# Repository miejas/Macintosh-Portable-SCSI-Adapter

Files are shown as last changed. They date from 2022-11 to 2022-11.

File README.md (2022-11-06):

# Macintosh Portable SCSI Adapter
An adapter from the 34-pin SCSI in the Portable to a standard 50-pin header.

Nothing fancy. Just rewires the pins in a convenient fashion, without the need for cobbling cables together. Additionally, there's an option to provide 5V to the TERMPWR pin. This could be achieved with a power diode for "high" current applications (like a SCSI to SD adapter) or a 220/330Ω resistor for current sensing only applications (as described in one of Woz's brain storm documents - can't seem to find it back).

The board has been succesfully produced by JLCPCB and Aisler, so I suppose any manufacturer of choice will do. It probably fits an entire host of different IDC connectors, but they've been succesfully fitted with Samtec's TST-125-01-G-D and TST-117-01-G-D. The 5V-GND-GND-12V "connector" could just be a floppy or hard drive wire bundle, recovered from an old ATX power supply.

The project is in KiCad format and is free for anyone to use, either personally or commercially. Since I have absolutely no experience in schematic and PCB design, there will probably be some errors and "donts". If you happen to find them, please let me know so I can adapt the design accordingly. Needless to say, but use of this project is at your own risk.

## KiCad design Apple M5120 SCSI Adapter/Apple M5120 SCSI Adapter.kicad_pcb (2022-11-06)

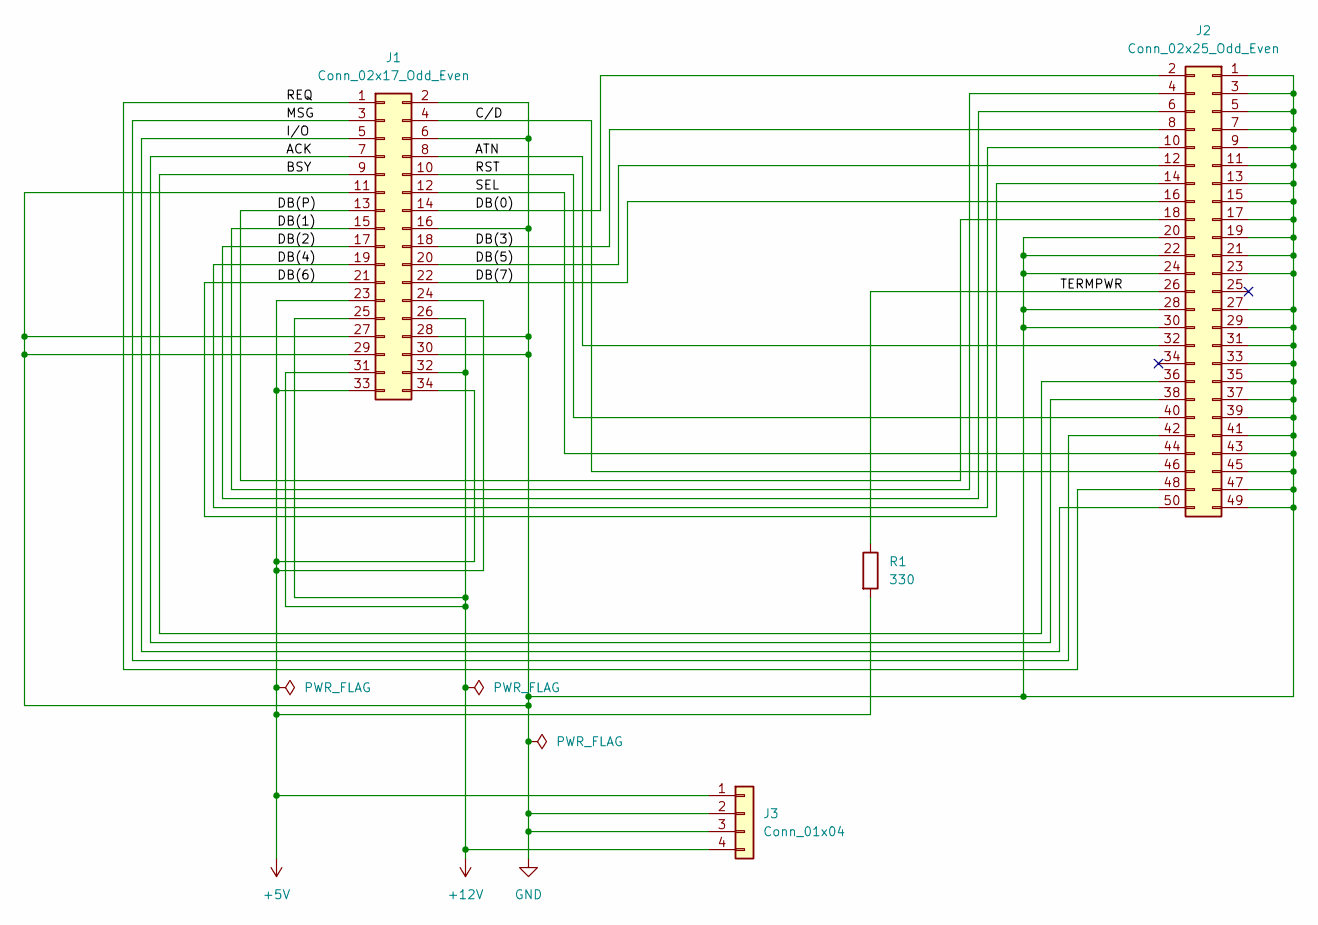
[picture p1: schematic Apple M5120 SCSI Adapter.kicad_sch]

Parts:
J1: Conn_02x17_Odd_Even; IDC-Header_2x17_P2.54mm_Vertical
J2: Conn_02x25_Odd_Even; IDC-Header_2x25_P2.54mm_Vertical
J3: Conn_01x04; SolderWire-0.75sqmm_1x04_P7mm_D1.25mm_OD3.5mm
R1: 330; R_Axial_DIN0207_L6.3mm_D2.5mm_P15.24mm_Horizontal

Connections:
+5V: J1.23, J1.24, J1.33, J1.34, J3.1, R1.2
+12V: J1.25, J1.26, J1.31, J1.32, J3.4
/ACK: J1.7, J2.38
/ATN: J1.8, J2.32
/BSY: J1.9, J2.36
/C/D: J1.4, J2.46
/DB(0): J1.14, J2.2
/DB(1): J1.15, J2.4
/DB(2): J1.17, J2.6
/DB(3): J1.18, J2.8
/DB(4): J1.19, J2.10
/DB(5): J1.20, J2.12
/DB(6): J1.21, J2.14
/DB(7): J1.22, J2.16
/DB(P): J1.13, J2.18
/I/O: J1.5, J2.50
/MSG: J1.3, J2.42
/REQ: J1.1, J2.48
/RST: J1.10, J2.40
/SEL: J1.12, J2.44
/TERMPWR: J2.26, R1.1
GND: J1.2, J1.6, J1.11, J1.16, J1.27, J1.28, J1.29, J1.30, J2.1, J2.3, J2.5, J2.7, J2.9, J2.11, J2.13, J2.15, J2.17, J2.19, J2.20, J2.21, J2.22, J2.23, J2.24, J2.27, J2.28, J2.29, J2.30, J2.31, J2.33, J2.35, J2.37, J2.39, J2.41, J2.43, J2.45, J2.47, J2.49, J3.2, J3.3

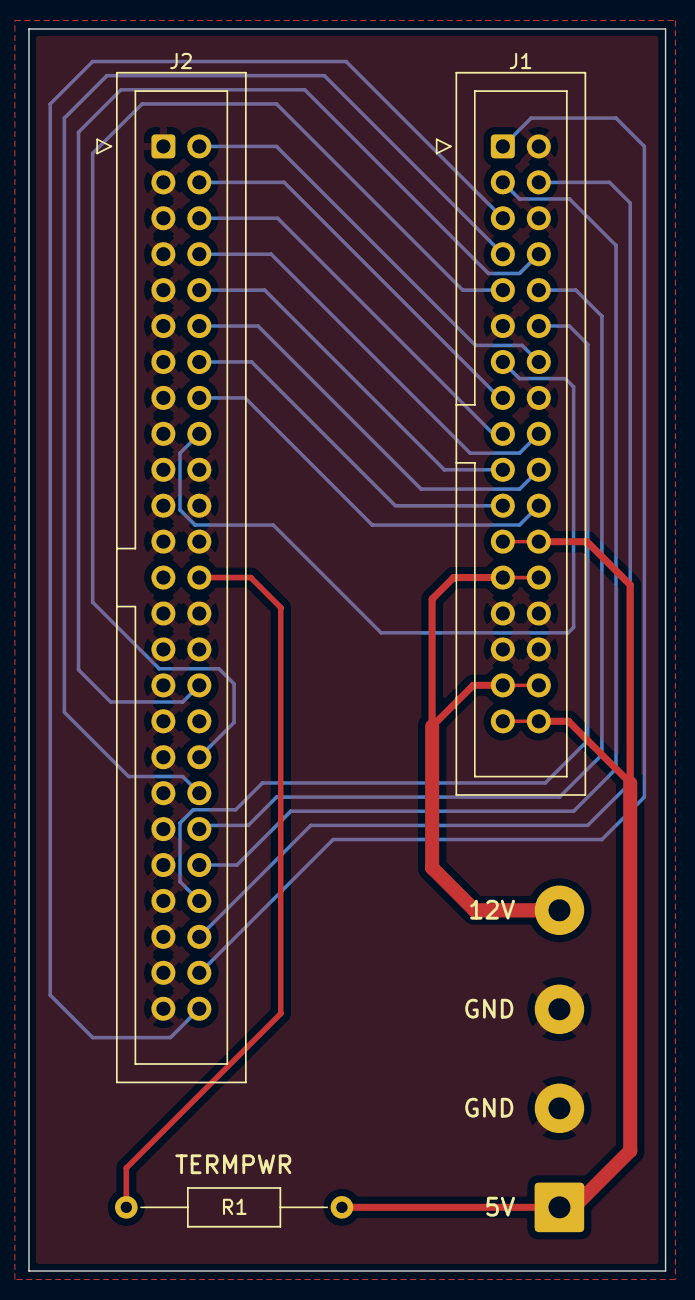
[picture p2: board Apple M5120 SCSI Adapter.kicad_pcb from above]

Board: 2 copper layers, 45.0 x 87.8 mm, 4 parts (0 on the bottom side), 22 nets.
